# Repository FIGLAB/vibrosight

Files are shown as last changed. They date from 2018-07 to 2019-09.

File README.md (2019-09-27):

# Vibrosight
This repository contains source files for the project Vibrosight. The research publication and more details of this project can be found here: https://yangzhang.dev/research/Vibrosight/Vibrosight.pdf

Project video can be found here: https://youtu.be/51XaZDki6yg

## Usage

We uploaded all data collected in the evaluation session and wrote a visualizer to render the data offline. To run the visualizer, please download the repository and execute the pre-compiled visualizer code (i.e., ./data and visualizer/visualizer.jar). 

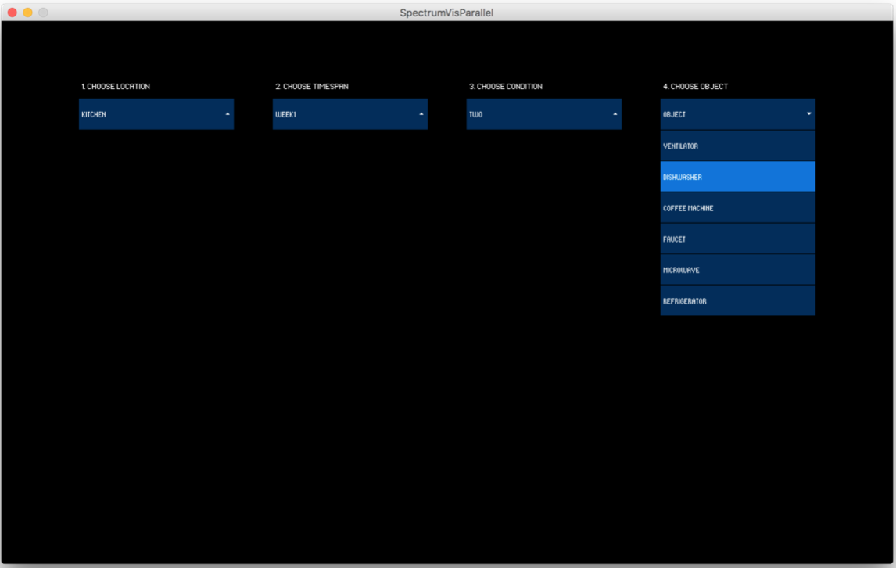
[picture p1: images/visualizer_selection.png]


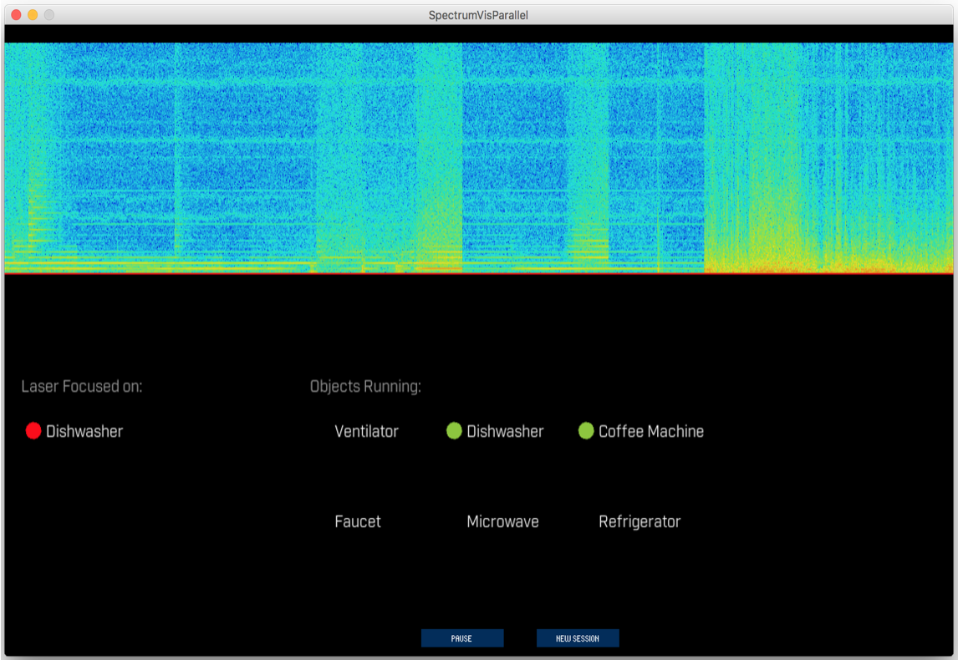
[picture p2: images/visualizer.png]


## Other resources
The hardware folder contains the Eagle PCB design files, including the schematic and the PCB layout:

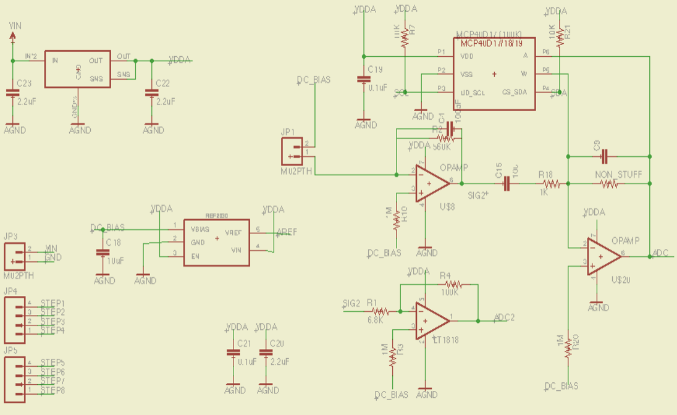
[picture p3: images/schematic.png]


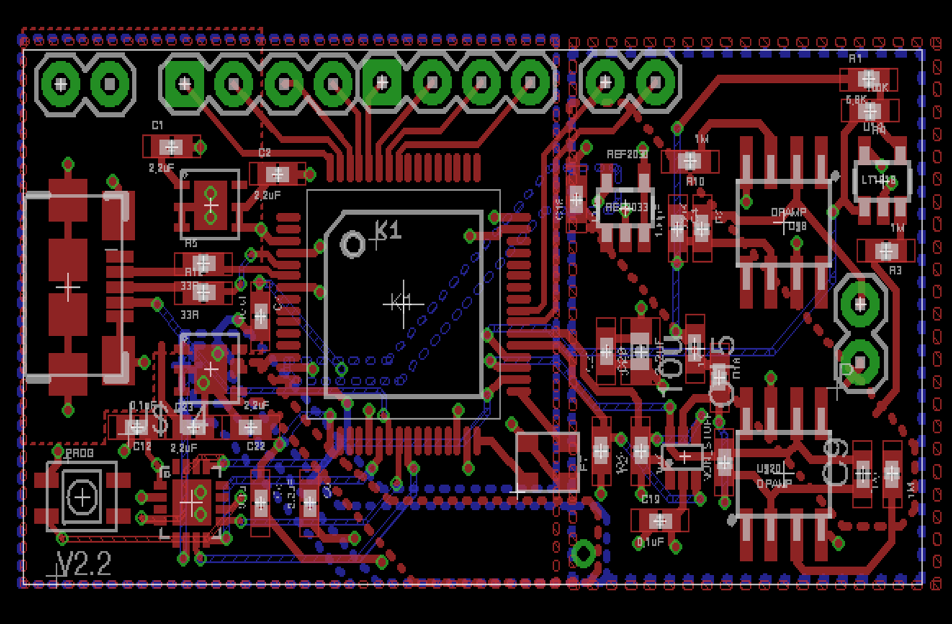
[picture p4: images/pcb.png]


The firmware is based on [Teensy 3.2](https://www.pjrc.com/teensy/teensy31.html) and can be edited and compiled with the [Arduino](https://www.arduino.cc) IDE. 

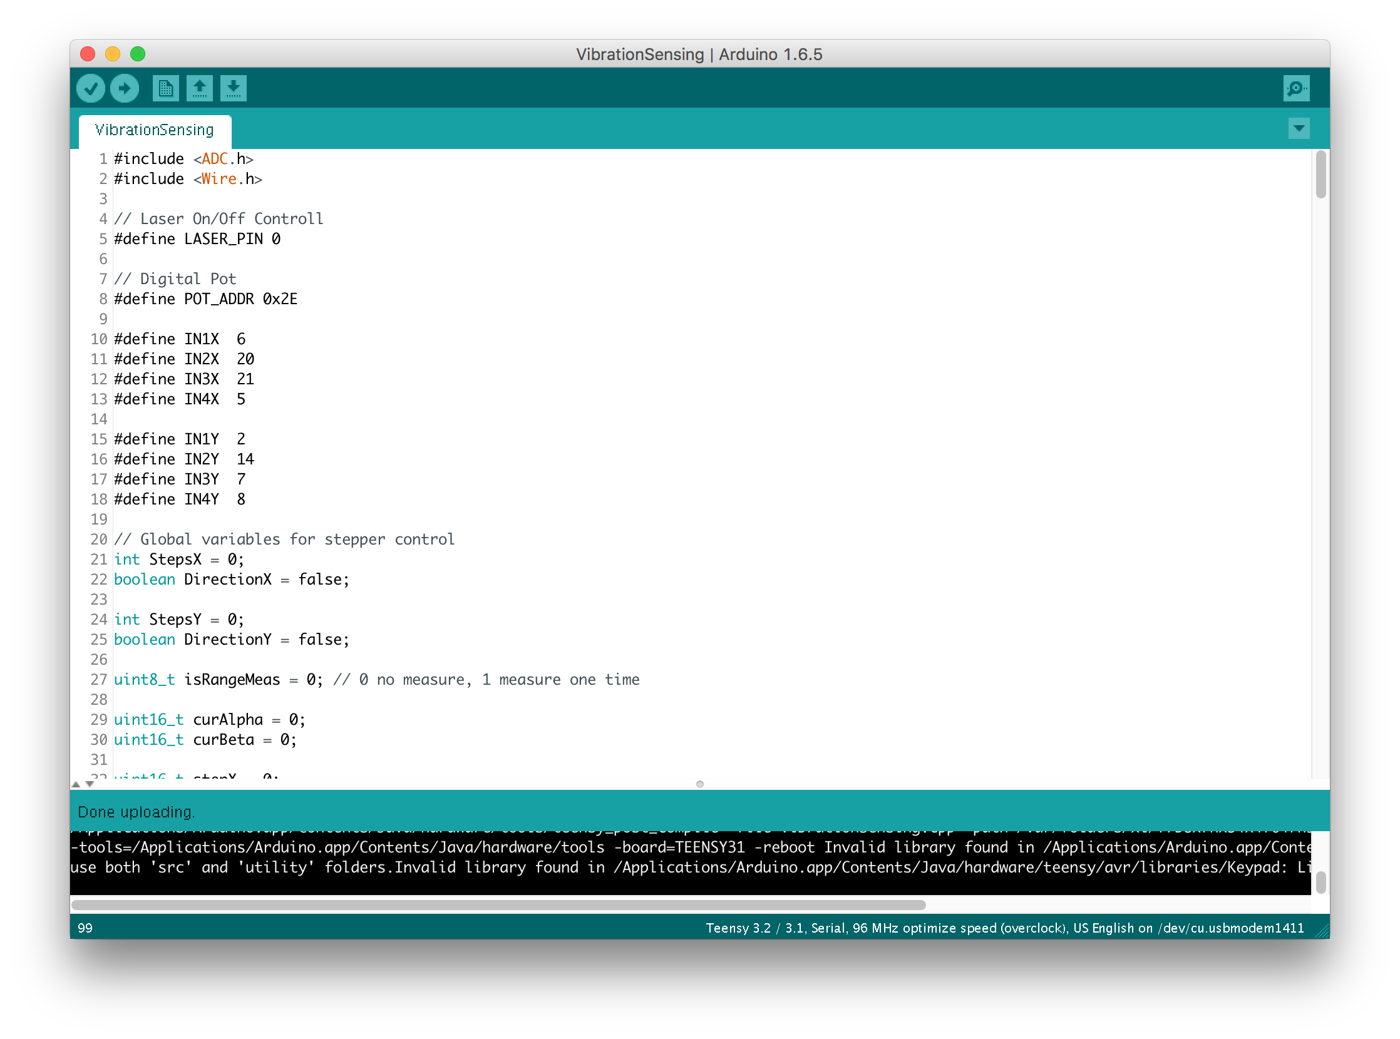
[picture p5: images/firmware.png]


A real-time visualzer that visualize data streamed from the sensor board:

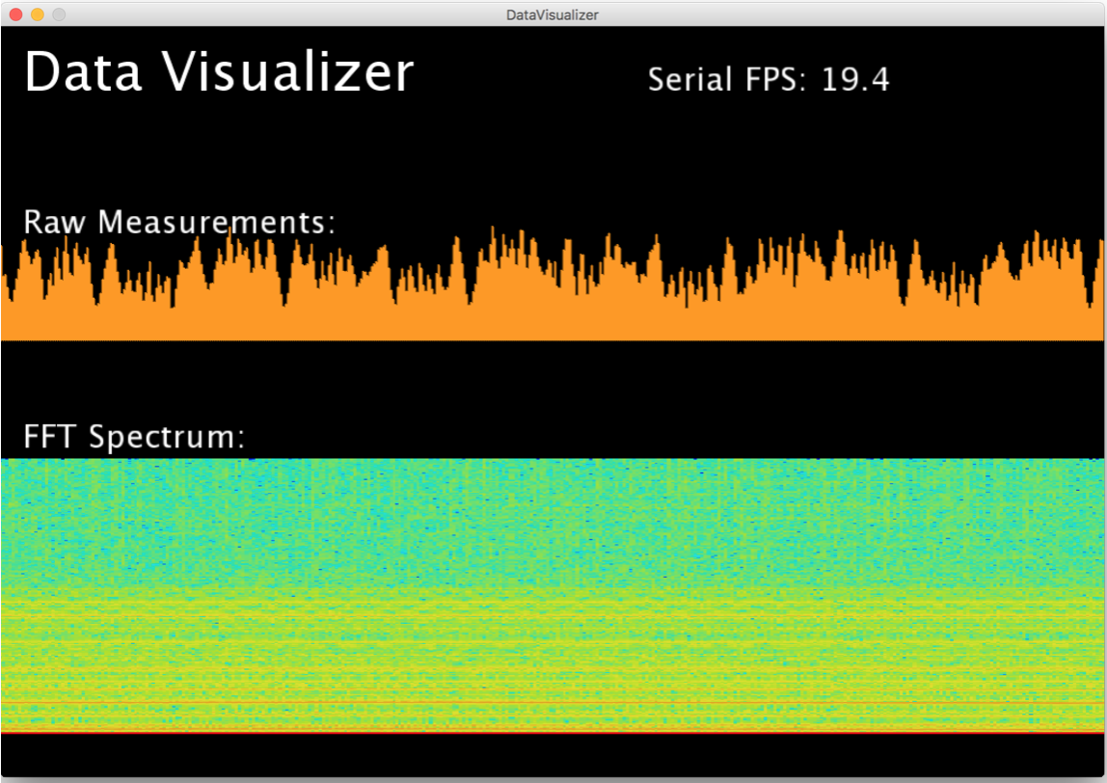
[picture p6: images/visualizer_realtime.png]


The 3D prints folder contains the model design files for the mirror-control platform:

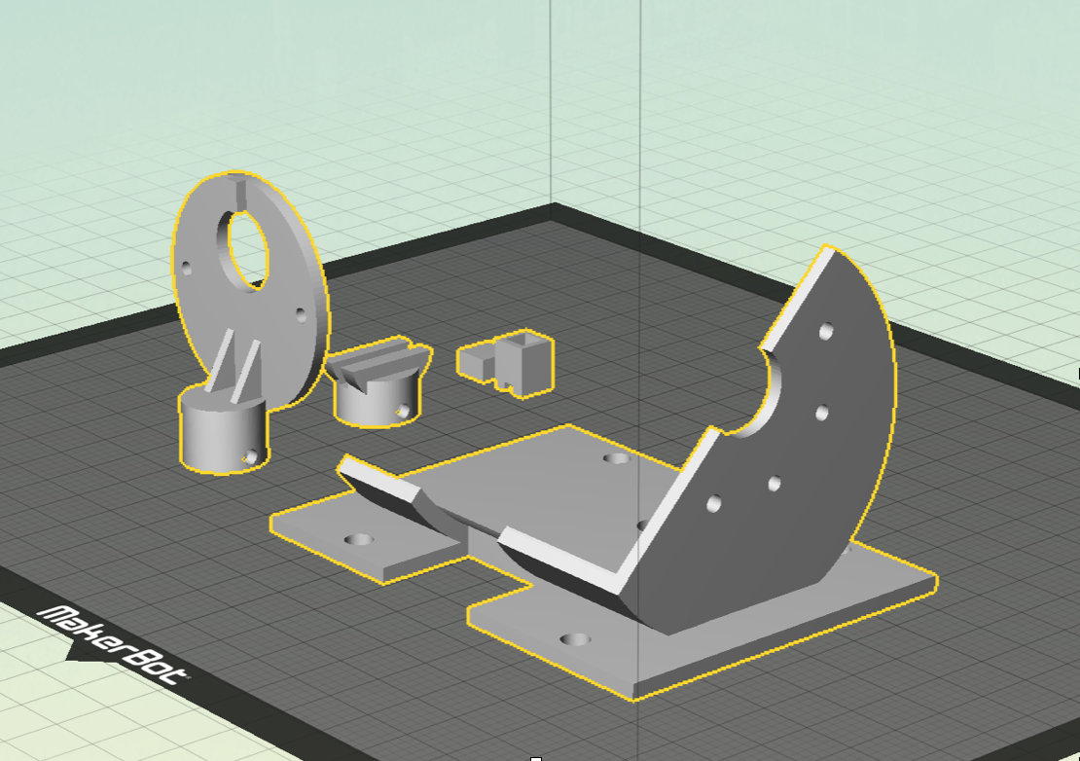
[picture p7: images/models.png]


## Known issues
The software was tested on MacBook (MacOS 10.14.5). For window systems the sensor board will enumerate with different names, which need to be updated in ./software/src/serial/SerialReader.java (line 28).

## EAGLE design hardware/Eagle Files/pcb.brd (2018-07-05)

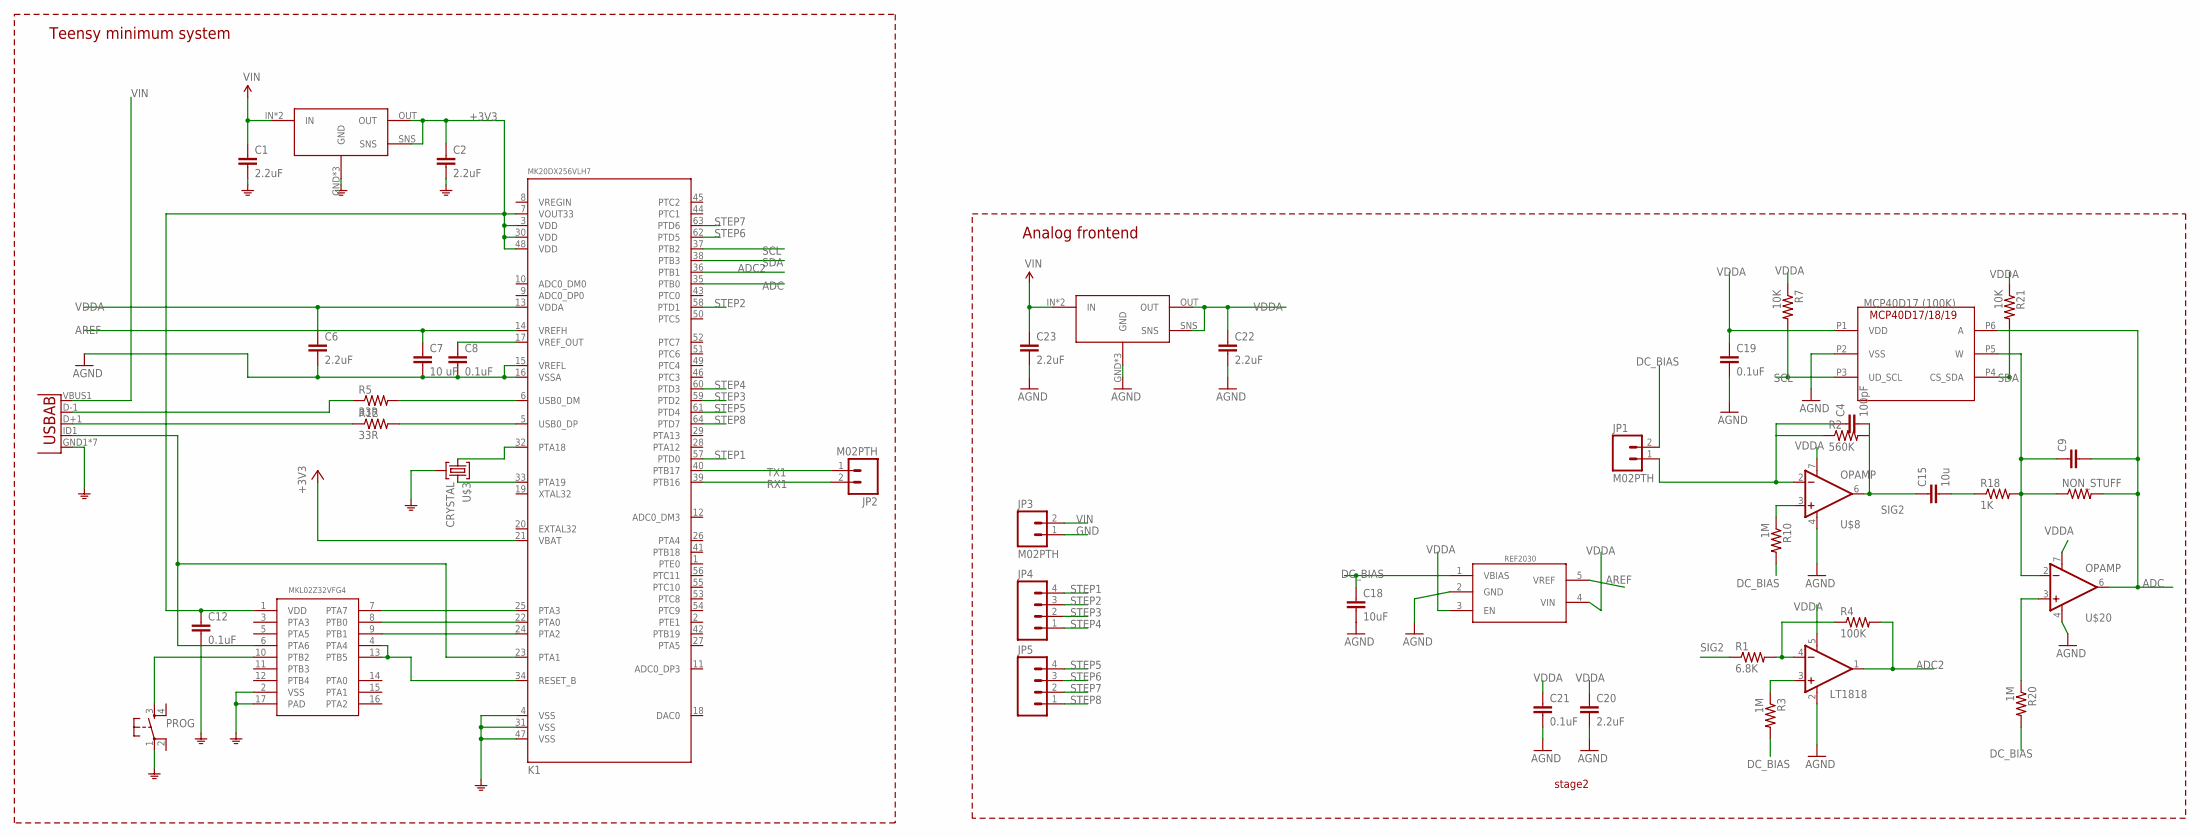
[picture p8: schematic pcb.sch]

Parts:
C1, C2, C6, C22, C23: 2.2uF; 0402-CAP
C4: 100pF; 0402-CAP
C7: 10 uF; 0402-CAP
C8, C12, C19, C21: 0.1uF; 0402-CAP
C9: C-EUC0402; C0402
C15: 10u; C0402
C18: 10uF; 0402-CAP
C20: 2.2uF; 0603-CAP
JP1, JP2, JP3: M02PTH; 1X02
JP4, JP5: M04PTH; 1X04
K1: MK20DX256VLH7; LQFP64-05
LP1, LP38691: LP38691SD; WSON_6
NON_STUFF: RESISTOR0402; 0402-RES
PROG: KMR211GLFS; TACTILE_SWITCH_SMD
R1: 6.8K; 0402-RES
R2: 560K; 0402-RES
R3, R10, R20: 1M; 0402-RES
R4: 100K; 0402-RES
R5, R12: 33R; 0402-RES
R7, R21: 10K; 0402-RES
R18: 1K; 0402-RES
REF2030: REF2033; SOT23
U5: USB""; USB-MICRO-SMD
U14: LT1818; SOT23-5
U$3: CRYSTAL
U$6: MCP40D17/18/19; SC70-6
U$8, U$20: OPAMP; 8-SOIC
U$14: MKL02Z32VFG4_; QFN16_3X3

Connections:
+3V3: C2.1, C12.1, K1.3 (VDD), K1.7 (VOUT33), K1.21 (VBAT), K1.30 (VDD), K1.48 (VDD), LP38691.OUT, LP38691.SNS, U$14.1 (VDD)
ADC: C9.2, K1.35 (PTB0), NON_STUFF.2, U$6.P6 (A), U$20.6 (OUT)
ADC2: K1.36 (PTB1), R4.2, U14.1 (OUT)
AGND: C6.2, C7.2, C8.2, C18.2, C19.2, C20.2, C21.2, C22.2, C23.2, K1.15 (VREFL), K1.16 (VSSA), LP1.GND, LP1.N/C (GND), LP1.THERMAL (GND), REF2030.2 (GND), U14.2 (V-), U$6.P2 (VSS), U$8.4 (V-), U$20.4 (V-)
AREF: C7.1, K1.14 (VREFH), REF2030.5 (VREF)
DC_BIAS: C18.1, JP1.2, R3.2, R10.2, R20.2, REF2030.1 (VBIAS)
GND: C1.2, C2.2, C12.2, JP3.1, K1.4 (VSS), K1.31 (VSS), K1.47 (VSS), LP38691.GND, LP38691.N/C (GND), LP38691.THERMAL (GND), PROG.1, U5.GND1 (GND), U5.P$1 (GND), U5.P$2 (GND), U5.P$3 (GND), U5.P$4 (GND), U5.P$5 (GND), U5.P$6 (GND), U$3.GND1 (2), U$3.GND2 (2), U$14.2 (VSS), U$14.17 (PAD)
unnamed: C4.1, JP1.1, R2.1, U$8.2 (-IN)
unnamed: R1.2, R4.1, U14.4 (-IN)
unnamed: C9.1, NON_STUFF.1, R18.2, U$6.P5 (W), U$20.2 (-IN)
unnamed: K1.32 (PTA18), U$3.SIG1 (1)
unnamed: K1.33 (PTA19), U$3.SIG2 (3)
unnamed: K1.24 (PTA2), U$14.9 (PTB1)
unnamed: R10.1, U$8.3 (+IN)
unnamed: K1.22 (PTA0), U$14.8 (PTB0)
unnamed: R3.1, U14.3 (+IN)
unnamed: C8.1, K1.17 (VREF_OUT)
unnamed: C15.2, R18.1
unnamed: K1.5 (USB0_DP), R12.2
unnamed: K1.6 (USB0_DM), R5.2
unnamed: R12.1, U5.D+1 (D+)
unnamed: R5.1, U5.D-1 (D-)
unnamed: K1.23 (PTA1), U5.ID1 (USBID), U$14.6 (PTA6)
unnamed: R20.1, U$20.3 (+IN)
unnamed: PROG.3, U$14.10 (PTB2)
unnamed: K1.25 (PTA3), U$14.7 (PTA7)
RST: K1.34 (RESET_B), U$14.4 (PTA4), U$14.13 (PTB5)
RX1: JP2.2, K1.39 (PTB16)
SCL: K1.37 (PTB2), R7.2, U$6.P3 (UD_SCL)
SDA: K1.38 (PTB3), R21.2, U$6.P4 (CS_SDA)
SIG2: C4.2, C15.1, R1.1, R2.2, U$8.6 (OUT)
STEP1: JP4.4, K1.57 (PTD0)
STEP2: JP4.3, K1.58 (PTD1)
STEP3: JP4.2, K1.59 (PTD2)
STEP4: JP4.1, K1.60 (PTD3)
STEP5: JP5.4, K1.61 (PTD4)
STEP6: JP5.3, K1.62 (PTD5)
STEP7: JP5.2, K1.63 (PTD6)
STEP8: JP5.1, K1.64 (PTD7)
TX1: JP2.1, K1.40 (PTB17)
VDDA: C6.1, C19.1, C20.1, C21.1, C22.1, K1.13 (VDDA), LP1.OUT, LP1.SNS, R7.1, R21.1, REF2030.3 (EN), REF2030.4 (VIN), U14.5 (V+), U$6.P1 (VDD), U$8.7 (V+), U$20.7 (V+)
VIN: C1.1, C23.1, JP3.2, LP1.IN, LP1.IN2 (IN), LP38691.IN, LP38691.IN2 (IN), U5.VBUS1 (VBUS)

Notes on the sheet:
Teensy minimum system
Analog frontend
MCP40D17 (100K)
stage2

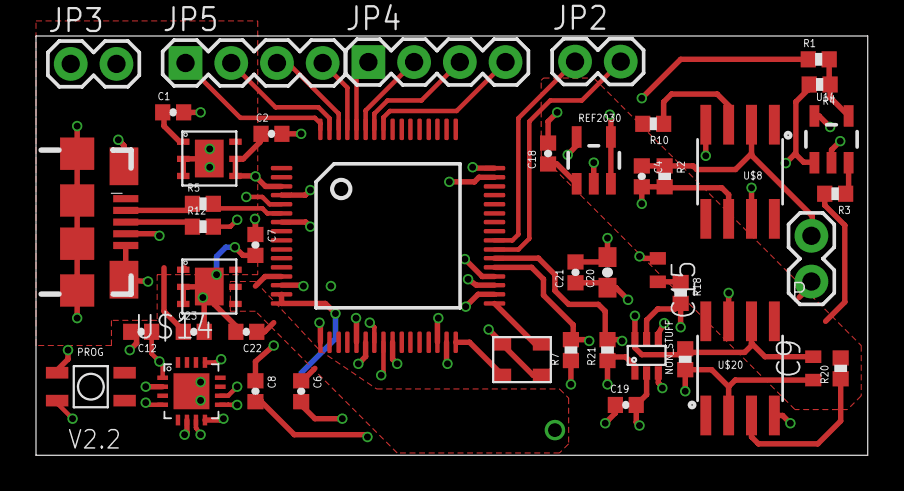
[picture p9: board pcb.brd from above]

Board: 4 copper layers, 46.2 x 23.3 mm, 44 parts (0 on the bottom side), 42 nets.

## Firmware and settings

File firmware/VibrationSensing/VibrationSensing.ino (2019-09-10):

#include <ADC.h>
#include <Wire.h>

// Laser On/Off Control
#define LASER_PIN 0

// Digital Pot
#define POT_ADDR 0x2E

#define IN1X  6
#define IN2X  20
#define IN3X  21
#define IN4X  5

#define IN1Y  2
#define IN2Y  14
#define IN3Y  7
#define IN4Y  8

// Global variables for stepper control
int StepsX = 0;
boolean DirectionX = false;

int StepsY = 0;
boolean DirectionY = false;

uint8_t isRangeMeas = 0; // 0 no measure, 1 measure one time

uint16_t curAlpha = 0;
uint16_t curBeta = 0;

uint16_t stepX = 0;
uint16_t stepY = 0;

float increStepY = 0;
float increStepX = 0;

unsigned long last_time;
unsigned long currentMillis;

// Tune this delay to change Stepper speed
int stepTime = 3000;

// Serial commands
byte commands[] = {0x00, 0x00, 0x00, 0x00, 0x00}; 
byte positionReady[] = {0x00, 0x00, 0x00}; 

// Tune this delay to change ADC sampling rate
int delayADCMicros = 200; 

// ADC buffer parameters
#define RAW_SIZE 256

uint16_t input[RAW_SIZE];

// Serial parameters
static const int baudrate = 460800;
uint8_t sendbuf[RAW_SIZE*2]; 
uint8_t delimiter[] = {0xff, 0xff, 0xff, 0xff};

// ADC parameters
ADC *adc = new ADC();
const int readPin = A2;
long t = 0;


void setup() {
  pinMode(readPin, INPUT);

  // Setup very fast ADC sampling rate
  adc->setAveraging(0);
  adc->setResolution(12); // 8, 10, 12, 16
  adc->setConversionSpeed(ADC_CONVERSION_SPEED::VERY_HIGH_SPEED);
  adc->setSamplingSpeed(ADC_SAMPLING_SPEED::VERY_HIGH_SPEED);
  //clearBit(&ADC0_CFG1, ADC_CFG1_ADICLK1_BIT);
  //clearBit(&ADC0_CFG1, ADC_CFG1_ADICLK0_BIT);
  adc->startContinuous(readPin, ADC_0);    
  adc->analogReadContinuous(ADC_0);
  Serial.begin(baudrate);

  // Digipot setting
  Wire.begin(); 
  Wire.beginTransmission(POT_ADDR);
  Wire.send(0x0);
  Wire.send(0x7f); // AFE Gain 100
  Wire.endTransmission();

  // Laser toggle control setting
  pinMode(LASER_PIN, OUTPUT);
  digitalWrite(LASER_PIN,LOW);

  // Steppers
  pinMode(IN1X, OUTPUT); 
  pinMode(IN2X, OUTPUT); 
  pinMode(IN3X, OUTPUT); 
  pinMode(IN4X, OUTPUT);
  
  pinMode(IN1Y, OUTPUT); 
  pinMode(IN2Y, OUTPUT); 
  pinMode(IN3Y, OUTPUT); 
  pinMode(IN4Y, OUTPUT);

  delay(100);

  // Recalibrate stepper position
  initializeZero();
}

void loop() {

  // Check motor control
  if (Serial.available() > 0) {
    
    digitalWrite(LASER_PIN, HIGH);
    
    int readLen = Serial.readBytes((char*)commands,5);

    // set stepper positions
    uint16_t beta = 0;
    uint16_t alpha = 0;
    uint8_t laserOn = 0;

    if(readLen != 0){
      beta  = commands[0];
      beta = beta <<8;
      beta = beta | commands[1];

      alpha  = commands[2];
      alpha = alpha <<8;
      alpha = alpha | commands[3];

      laserOn = commands[4];
    }

    if(alpha > curAlpha){
      stepX = alpha - curAlpha;
      DirectionX = 1;
    }else{
      stepX = curAlpha - alpha;
      DirectionX = 0;
    }

    if(beta > curBeta){
      stepY = beta - curBeta;
      DirectionY = 1;
      curBeta = beta;
    }else{
      stepY = curBeta - beta;
      DirectionY = 0;
    }

      while(stepY>0){ 
        currentMillis = micros();
        if(currentMillis-last_time>=stepTime){
          stepperY(); 
          last_time=micros();
          stepY--;
        }
      }

      
      while(stepX>0){ 
        currentMillis = micros();
        if(currentMillis-last_time>=stepTime){
          stepperX(); 
          last_time=micros();
          stepX--;
        }
      }

    curAlpha = alpha;
    curBeta = beta;
    
    if(laserOn != 0){
      digitalWrite(LASER_PIN, LOW);
    }
    
    sendReadySig();
  }

  // Start streaming ADC measurements
  sendRawData();
}


void initializeZero(){
  uint16_t count = 1024;
  while(count>0){
    currentMillis = micros();
    if(currentMillis-last_time>=stepTime){
      stepperX();  // one step
      stepperY();  // one step
      last_time=micros();
      count--;
    }
  }
}

void sendReadySig(){
  Serial.write(positionReady, sizeof(positionReady));
  Serial.write(delimiter, sizeof(delimiter));
}

void sendRawData() {

  int delayed = (micros() - t);
  
  if(delayed < delayADCMicros){
    delayMicroseconds(delayADCMicros - delayed);
  }


  while(!adc->isComplete(0)) // dump the old measurement
       ;
       
  for (int i = 0; i < RAW_SIZE; i++) {
      
        /* check before read */
        while(!adc->isComplete(0))
          ;
        input[i] = adc->analogReadContinuous(); 
        
        if(i!= RAW_SIZE - 1){
          delayMicroseconds(delayADCMicros);
        }
    }

    t = micros();
    
    for(int i=0; i<RAW_SIZE; i++) {
        uint16_t v = clamp_u16(input[i]);
        sendbuf[2*i] = v & 0xff;
        sendbuf[2*i+1] = v >> 8;
    }

    Serial.write(sendbuf, sizeof(sendbuf));
    Serial.write(delimiter, sizeof(delimiter));
}

static inline uint16_t clamp_u16(int v) {
  // leave 65535 (0xffff) for the terminator
  if(v > 65534) return 65534; 
  if(v < 0) return 0;
  return (uint16_t)v;
}

// Stepper helper functions
void stepperX(){
    switch(StepsX){
       case 0:
         digitalWrite(IN1X, LOW); 
         digitalWrite(IN2X, LOW);
         digitalWrite(IN3X, LOW);
         digitalWrite(IN4X, HIGH);
       break; 
       case 1:
         digitalWrite(IN1X, LOW); 
         digitalWrite(IN2X, LOW);
         digitalWrite(IN3X, HIGH);
         digitalWrite(IN4X, HIGH);
       break; 
       case 2:
         digitalWrite(IN1X, LOW); 
         digitalWrite(IN2X, LOW);
         digitalWrite(IN3X, HIGH);
         digitalWrite(IN4X, LOW);
       break; 
       case 3:
         digitalWrite(IN1X, LOW); 
         digitalWrite(IN2X, HIGH);
         digitalWrite(IN3X, HIGH);
         digitalWrite(IN4X, LOW);
       break; 
       case 4:
         digitalWrite(IN1X, LOW); 
         digitalWrite(IN2X, HIGH);
         digitalWrite(IN3X, LOW);
         digitalWrite(IN4X, LOW);
       break; 
       case 5:
         digitalWrite(IN1X, HIGH); 
         digitalWrite(IN2X, HIGH);
         digitalWrite(IN3X, LOW);
         digitalWrite(IN4X, LOW);
       break; 
         case 6:
         digitalWrite(IN1X, HIGH); 
         digitalWrite(IN2X, LOW);
         digitalWrite(IN3X, LOW);
         digitalWrite(IN4X, LOW);
       break; 
       case 7:
         digitalWrite(IN1X, HIGH); 
         digitalWrite(IN2X, LOW);
         digitalWrite(IN3X, LOW);
         digitalWrite(IN4X, HIGH);
       break; 
       default:
         digitalWrite(IN1X, LOW); 
         digitalWrite(IN2X, LOW);
         digitalWrite(IN3X, LOW);
         digitalWrite(IN4X, LOW);
       break; 
    }
    SetDirectionX();
} 

void stepperY(){
    switch(StepsY){
       case 0:
         digitalWrite(IN1Y, LOW); 
         digitalWrite(IN2Y, LOW);
         digitalWrite(IN3Y, LOW);
         digitalWrite(IN4Y, HIGH);
       break; 
       case 1:
         digitalWrite(IN1Y, LOW); 
         digitalWrite(IN2Y, LOW);
         digitalWrite(IN3Y, HIGH);
         digitalWrite(IN4Y, HIGH);
       break; 
       case 2:
         digitalWrite(IN1Y, LOW); 
         digitalWrite(IN2Y, LOW);
         digitalWrite(IN3Y, HIGH);
         digitalWrite(IN4Y, LOW);
       break; 
       case 3:
         digitalWrite(IN1Y, LOW); 
         digitalWrite(IN2Y, HIGH);
         digitalWrite(IN3Y, HIGH);
         digitalWrite(IN4Y, LOW);
       break; 
       case 4:
         digitalWrite(IN1Y, LOW); 
         digitalWrite(IN2Y, HIGH);
         digitalWrite(IN3Y, LOW);
         digitalWrite(IN4Y, LOW);
       break; 
       case 5:
         digitalWrite(IN1Y, HIGH); 
         digitalWrite(IN2Y, HIGH);
         digitalWrite(IN3Y, LOW);
         digitalWrite(IN4Y, LOW);
       break; 
         case 6:
         digitalWrite(IN1Y, HIGH); 
         digitalWrite(IN2Y, LOW);
         digitalWrite(IN3Y, LOW);
         digitalWrite(IN4Y, LOW);
       break; 
       case 7:
         digitalWrite(IN1Y, HIGH); 
         digitalWrite(IN2Y, LOW);
         digitalWrite(IN3Y, LOW);
         digitalWrite(IN4Y, HIGH);
       break; 
       default:
         digitalWrite(IN1Y, LOW); 
         digitalWrite(IN2Y, LOW);
         digitalWrite(IN3Y, LOW);
         digitalWrite(IN4Y, LOW);
       break; 
    }
    SetDirectionY();
}

void SetDirectionX(){
  if(DirectionX==1){StepsX++;}
  if(DirectionX==0){StepsX--;}
  if(StepsX>7){StepsX=0;}
  if(StepsX<0){StepsX=7;}
}

void SetDirectionY(){
  if(DirectionY==1){StepsY++;}
  if(DirectionY==0){StepsY--;}
  if(StepsY>7){StepsY=0;}
  if(StepsY<0){StepsY=7;}
}

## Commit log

2018-07-05 Added hardware design files and datasheets.
    [pcb.brd, pcb.sch]
2018-07-05 Added 3D print MakerBot file
2018-07-26 Ported data and visualizer
    [FFT_Buffers_Bench.csv, FFT_Buffers_Bicycle.csv, FFT_Buffers_CNC.csv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]
2019-06-10 change for TeamZ trip
    [FFT_Buffers_Bench.csv, FFT_Buffers_Bicycle.csv, FFT_Buffers_CNC.csv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]
2019-06-10 Revert "change for TeamZ trip"
    This reverts commit 97e59d618e21542305b762cd5ba13221074f8e74.
    [FFT_Buffers_Bench.csv, FFT_Buffers_Bicycle.csv, FFT_Buffers_CNC.csv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]
2019-09-10 Updated the firmware code to be compatible with teensyduino 1.47 (latest)

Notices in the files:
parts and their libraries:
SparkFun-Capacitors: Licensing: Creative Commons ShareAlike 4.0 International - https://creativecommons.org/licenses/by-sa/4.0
